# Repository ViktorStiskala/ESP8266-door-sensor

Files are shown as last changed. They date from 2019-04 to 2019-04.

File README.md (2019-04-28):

# ESP8266 low power door sensor

This design represents a small sensor intended to be triggered by a magnetic reed switch. It wakes upon closing the contact, reporting the information to the internet and going back to sleep. All while retaining minimum power consumption.

## PCB design

- [Schematic design](pcb/schematic/Door.pdf)
- [Gerblook](http://gerblook.org/pcb/wmdqLb5envAoFVmN6yVcNm)

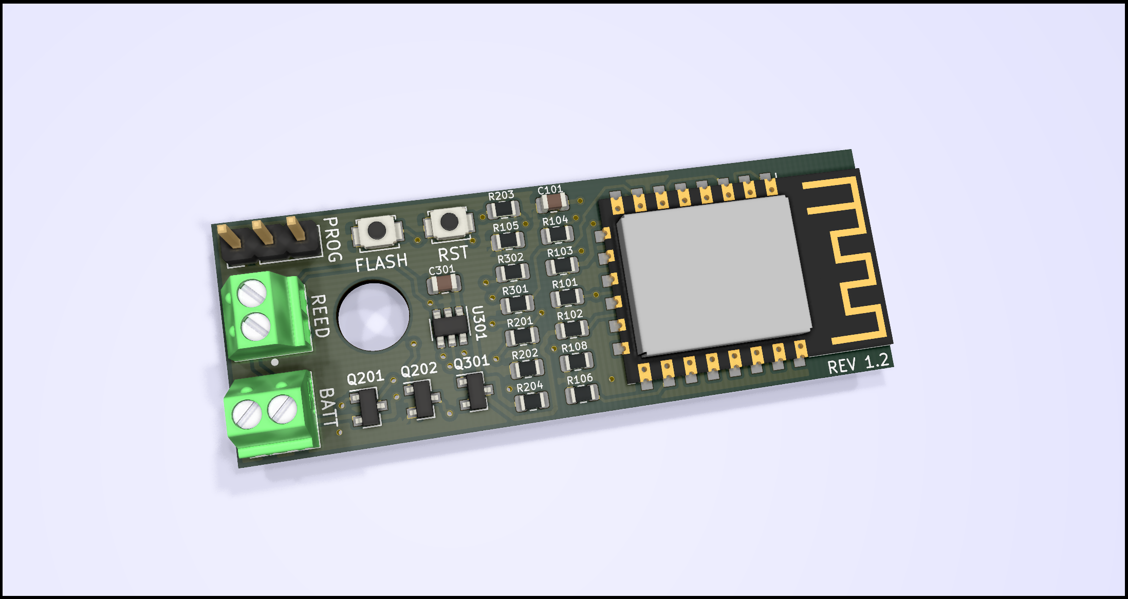
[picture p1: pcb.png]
PCB


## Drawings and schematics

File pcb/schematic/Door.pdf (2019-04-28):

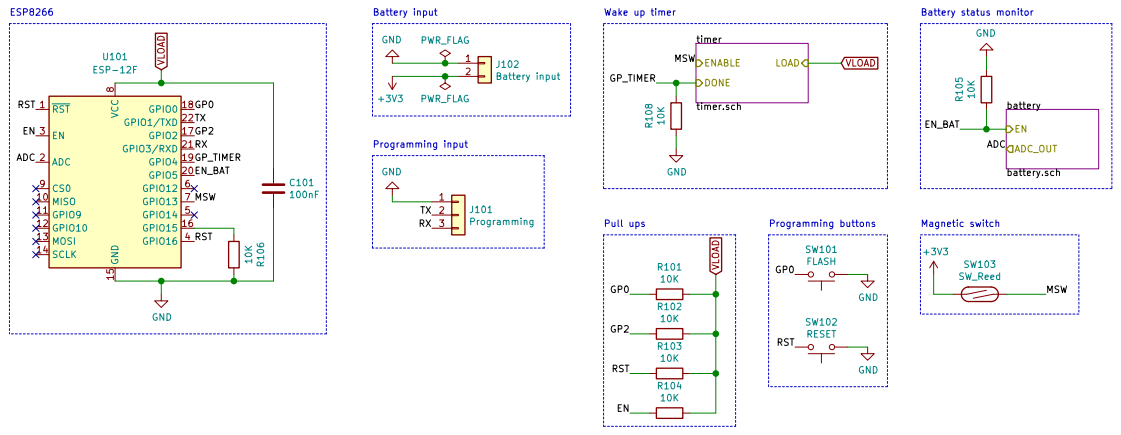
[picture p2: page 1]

Magnetic switch RST SW102 RESET

Id: 1/3 Title: Door sensor File: Door.sch Sheet: /

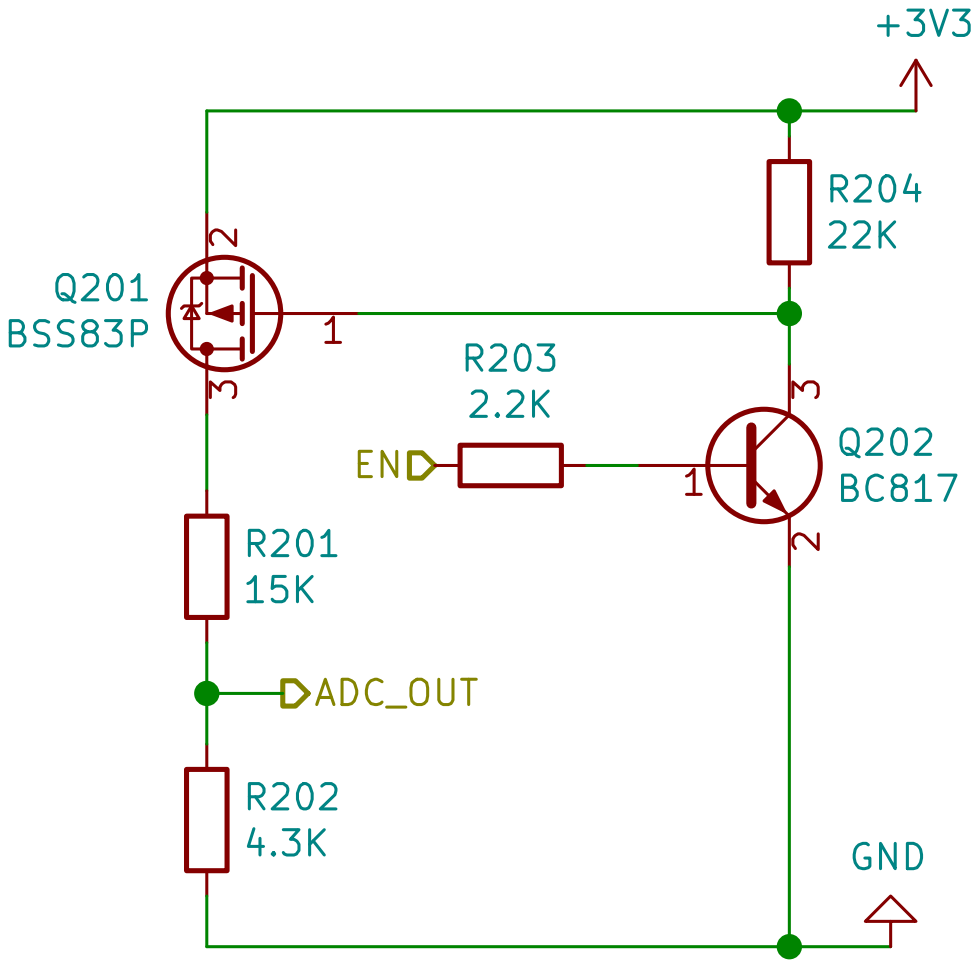
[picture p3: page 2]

Sheet: /battery/
File: battery.sch
Id: 2/3 Title: Battery status monitor

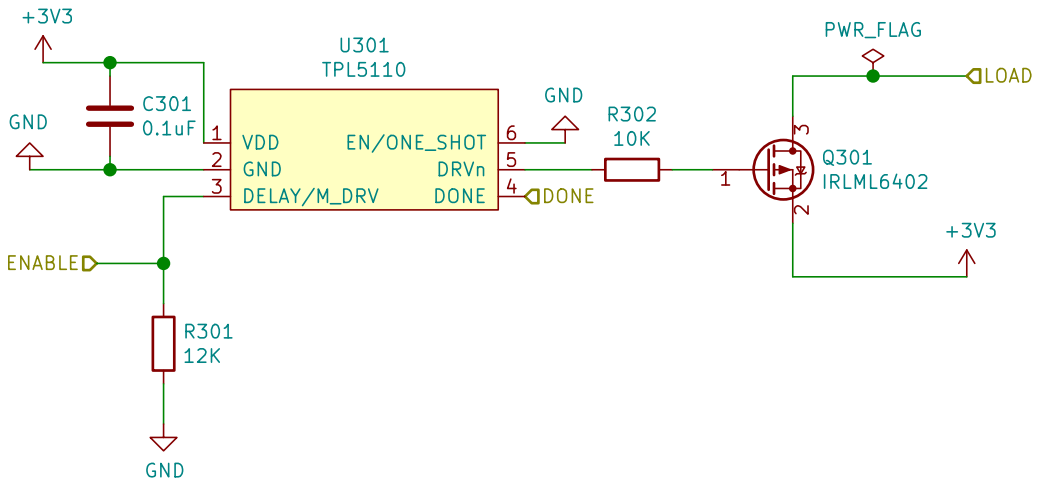
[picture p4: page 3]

Id: 3/3 Title: TPL5110 low power timer File: timer.sch Sheet: /timer/

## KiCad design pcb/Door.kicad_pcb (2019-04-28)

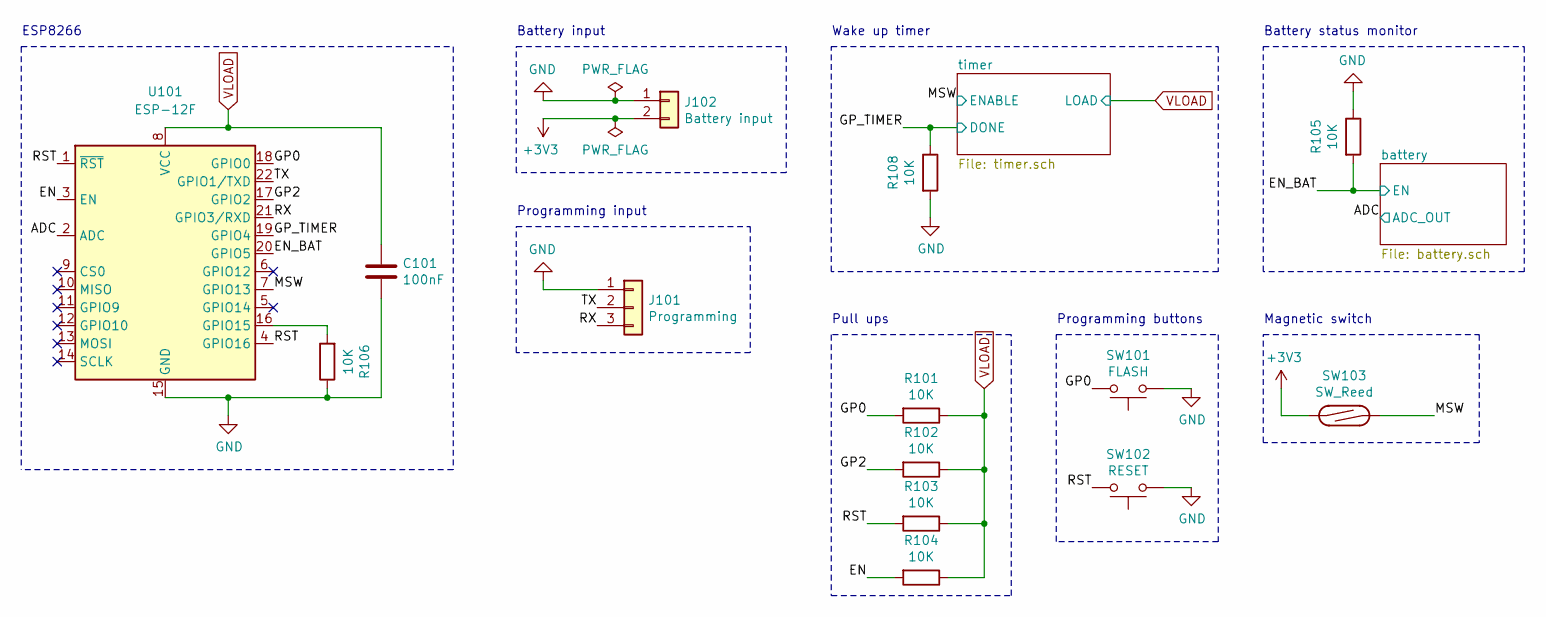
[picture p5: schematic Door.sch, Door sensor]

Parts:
C101: 100nF; C_0805_2012Metric
J101: Programming; PinHeader_1x03_P2.54mm_Vertical
J102: Battery input; PH_MPT_0,5_2-2,54
R101, R102, R103, R104, R105, R106, R108: 10K; R_0805_2012Metric
SW101: FLASH; SW_SPST_B3U-1000P
SW102: RESET; SW_SPST_B3U-1000P
SW103: SW_Reed; PH_MPT_0,5_2-2,54
U101: ESP-12F; ESP-12E

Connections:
+3V3: J102.2, SW103.2; also elsewhere on the board
/ADC: U101.2 (ADC); also elsewhere on the board
/EN: R104.2, U101.3 (EN)
/EN_BAT: R105.2, U101.20 (GPIO5); also elsewhere on the board
/GP0: R101.2, SW101.2, U101.18 (GPIO0)
/GP2: R102.2, U101.17 (GPIO2)
/GP_TIMER: R108.1, U101.19 (GPIO4); also elsewhere on the board
/MSW: SW103.1, U101.7 (GPIO13); also elsewhere on the board
/RST: R103.2, SW102.2, U101.1 (~RST), U101.4 (GPIO16)
/RX: J101.3, U101.21 (GPIO3/RXD)
/TX: J101.2, U101.22 (GPIO1/TXD)
GND: C101.2, J101.1, J102.1, R105.1, R106.1, R108.2, SW101.1, SW102.1, U101.15 (GND); also elsewhere on the board
unnamed: R106.2, U101.16 (GPIO15)
VLOAD: C101.1, R101.1, R102.1, R103.1, R104.1, U101.8 (VCC); also elsewhere on the board

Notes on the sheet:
Pull ups
Battery input
Programming input
Battery status monitor
Wake up timer
ESP8266
Programming buttons
Magnetic switch

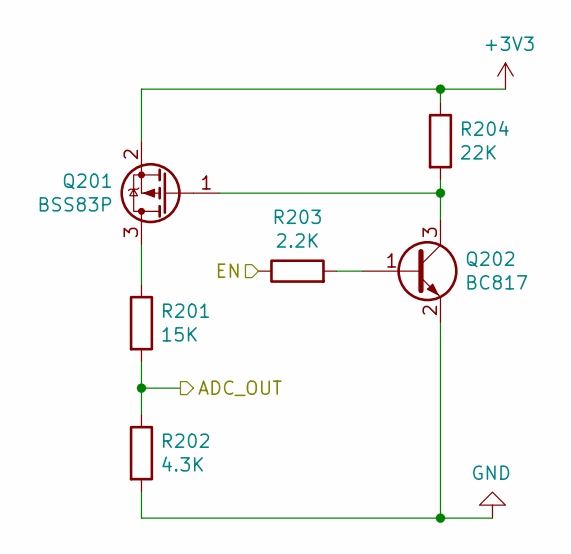
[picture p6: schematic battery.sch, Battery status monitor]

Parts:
Q201: BSS83P; SOT-23
Q202: BC817; SOT-23
R201: 15K; R_0805_2012Metric
R202: 4.3K; R_0805_2012Metric
R203: 2.2K; R_0805_2012Metric
R204: 22K; R_0805_2012Metric

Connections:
+3V3: Q201.2 (S), R204.1; also elsewhere on the board
/ADC: R201.2, R202.1; also elsewhere on the board
/EN_BAT: R203.1; also elsewhere on the board
GND: Q202.2 (E), R202.2; also elsewhere on the board
unnamed: Q201.1 (G), Q202.3 (C), R204.2
unnamed: Q201.3 (D), R201.1
unnamed: Q202.1 (B), R203.2

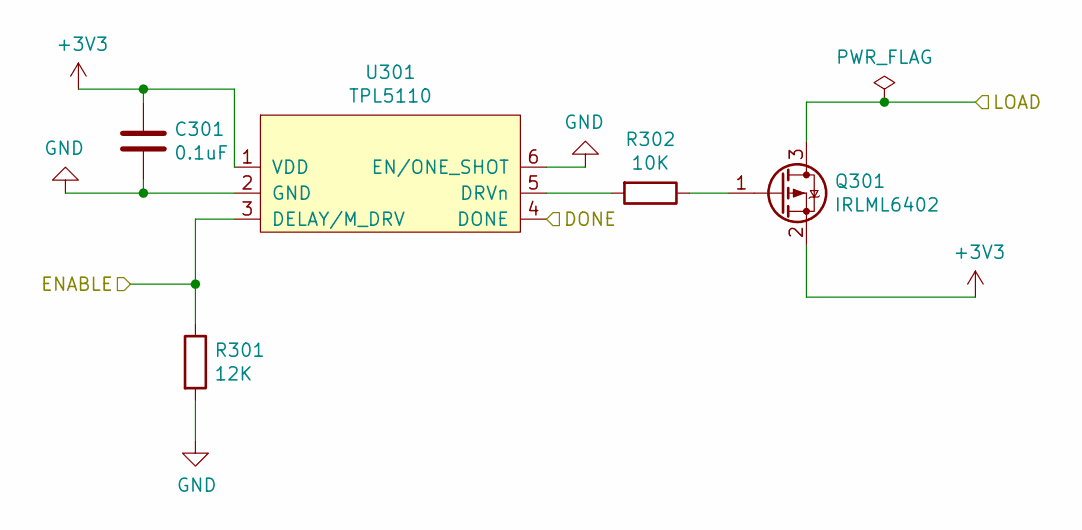
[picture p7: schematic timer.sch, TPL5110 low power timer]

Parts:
C301: 0.1uF; C_0805_2012Metric
Q301: IRLML6402; SOT-23
R301: 12K; R_0805_2012Metric
R302: 10K; R_0805_2012Metric
U301: TPL5110; SOT-23-6

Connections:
+3V3: C301.1, Q301.2 (S), U301.1 (VDD); also elsewhere on the board
/GP_TIMER: U301.4 (DONE); also elsewhere on the board
/MSW: R301.1, U301.3 (DELAY/M_DRV); also elsewhere on the board
GND: C301.2, R301.2, U301.2 (GND), U301.6 (EN/ONE_SHOT); also elsewhere on the board
unnamed: Q301.1 (G), R302.1
unnamed: R302.2, U301.5 (DRVn)
VLOAD: Q301.3 (D); also elsewhere on the board

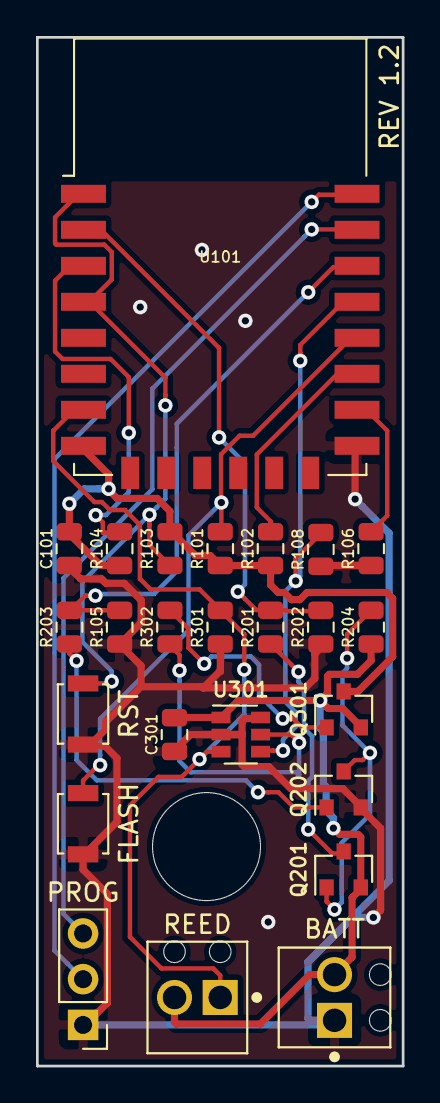
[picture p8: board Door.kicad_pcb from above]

Board: 2 copper layers, 20.3 x 57.1 mm, 25 parts (0 on the bottom side), 19 nets.

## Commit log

2019-04-28 Revision 1.2
    [Door.kicad_pcb, Door.sch, battery.sch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]
2019-04-28 Changed directory structure
    [Door.kicad_pcb, Door.sch, battery.sch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]
2019-04-28 Hole clearance update
    [Door.kicad_pcb]
